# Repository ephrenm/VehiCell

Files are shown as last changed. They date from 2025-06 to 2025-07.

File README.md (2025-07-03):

**Goal:** Create a single module which combines vehicle CANbus, GPS and accelerometer data into a single stream to be stored in a cloud database using LTE CAT-M1 cellular technology.

**Current Task:** Routing

Current WIP layout:

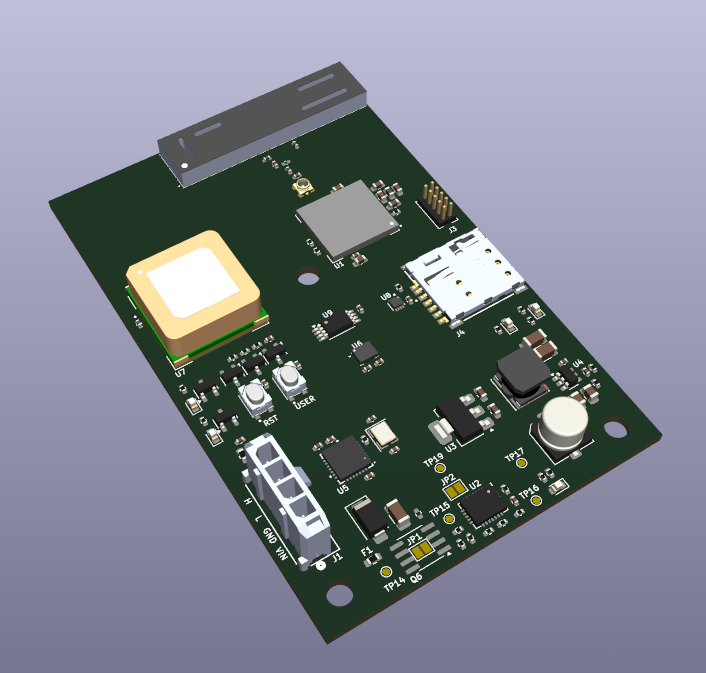
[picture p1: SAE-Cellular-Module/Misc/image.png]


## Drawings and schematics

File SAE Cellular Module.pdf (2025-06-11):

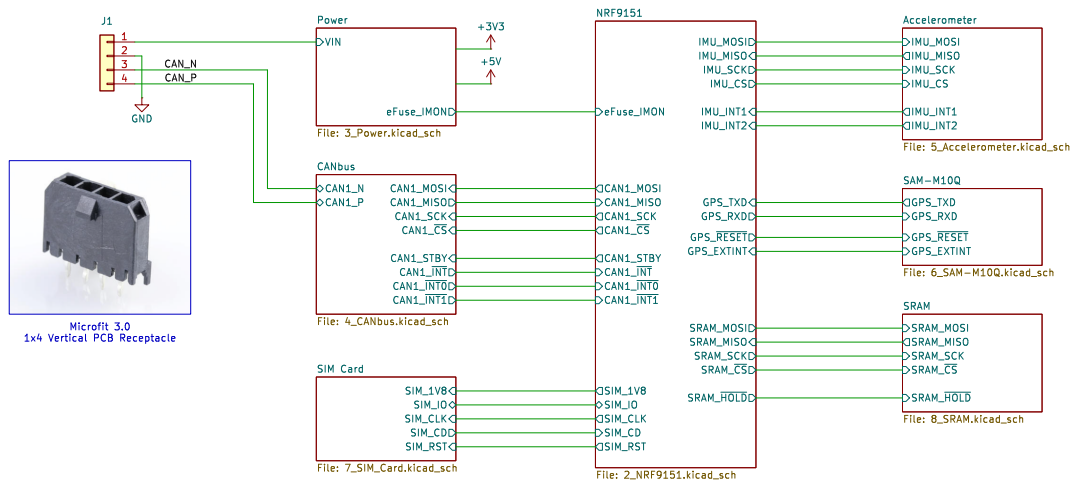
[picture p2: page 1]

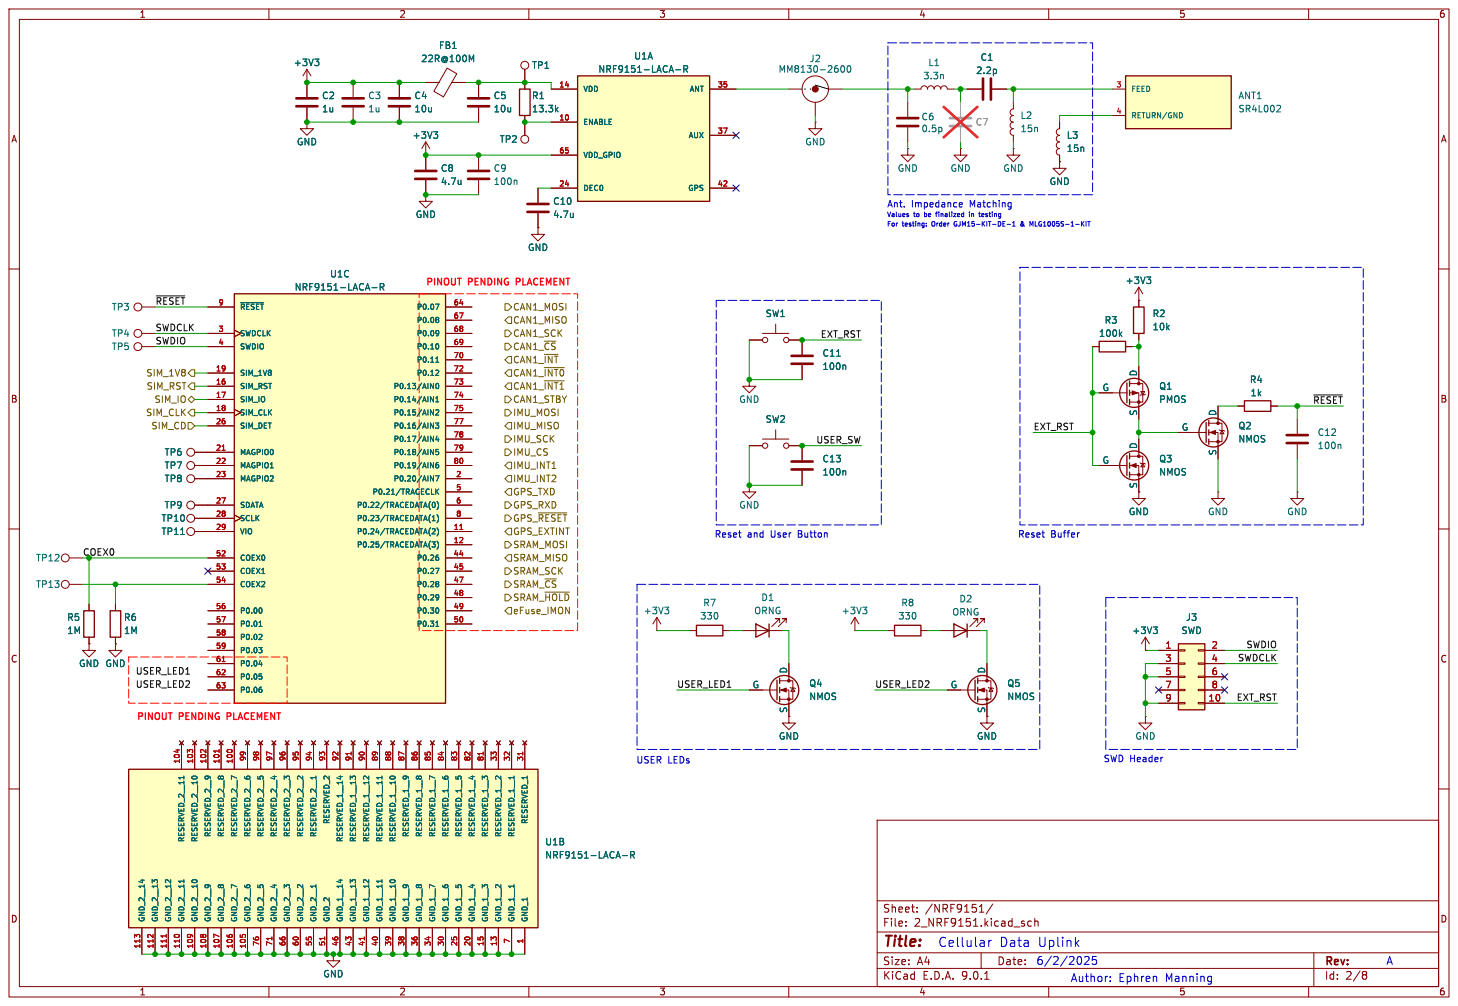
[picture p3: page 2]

Id: 2/8 Title: File: 2_NRF9151.kicad_sch Sheet: /NRF9151/ GND

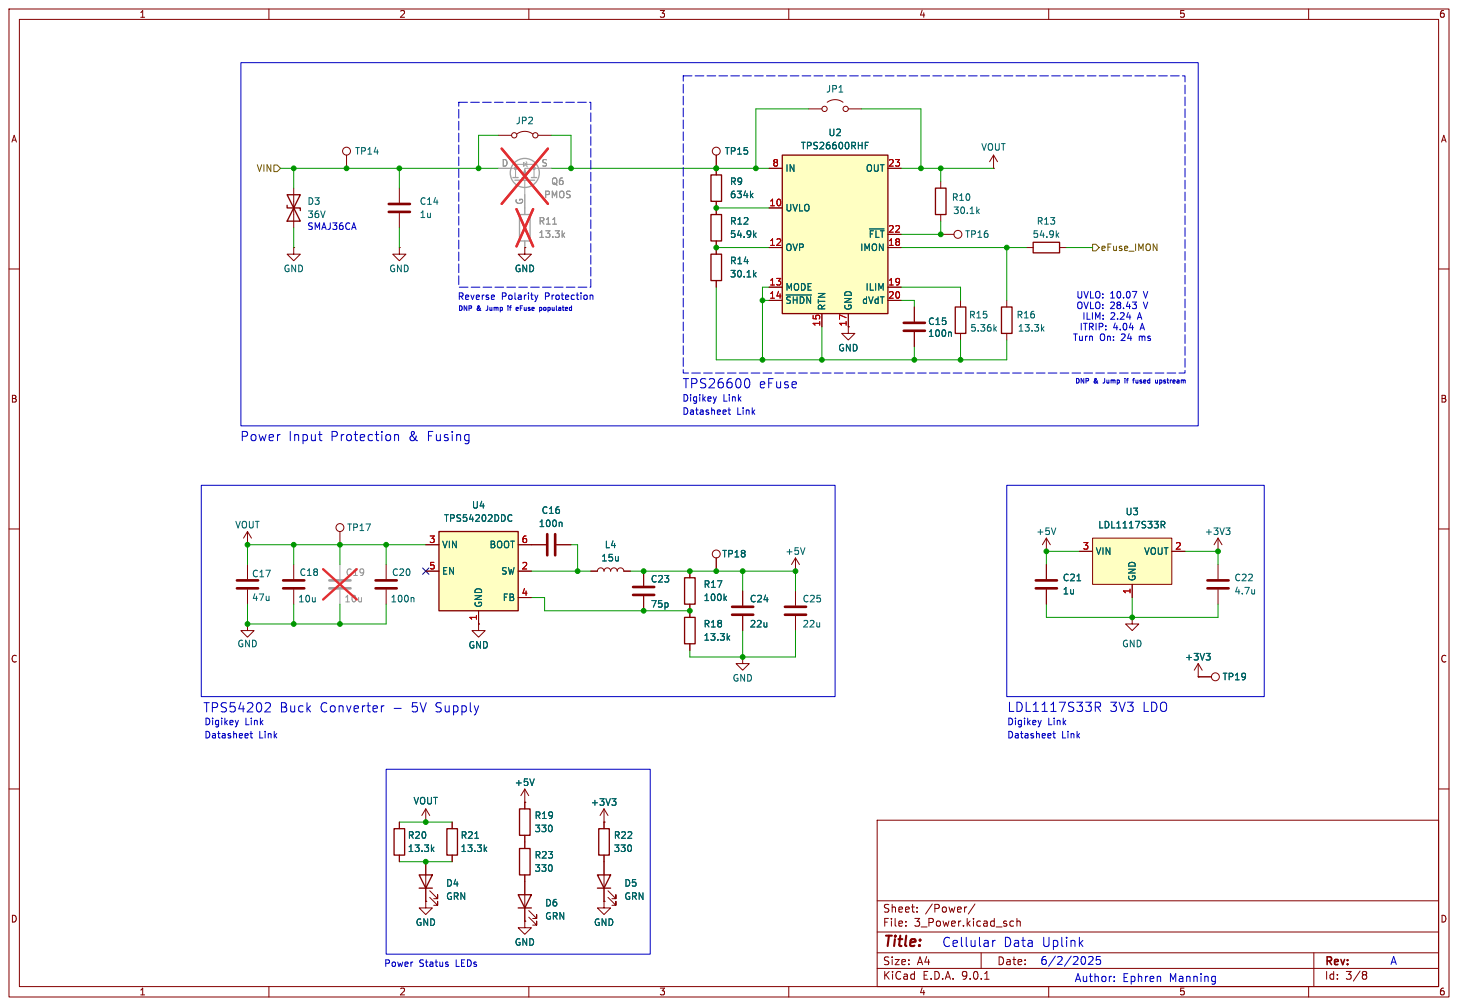
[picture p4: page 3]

1 BOOT 6 SW 2 FB 4 U4 TPS54202DDC GND

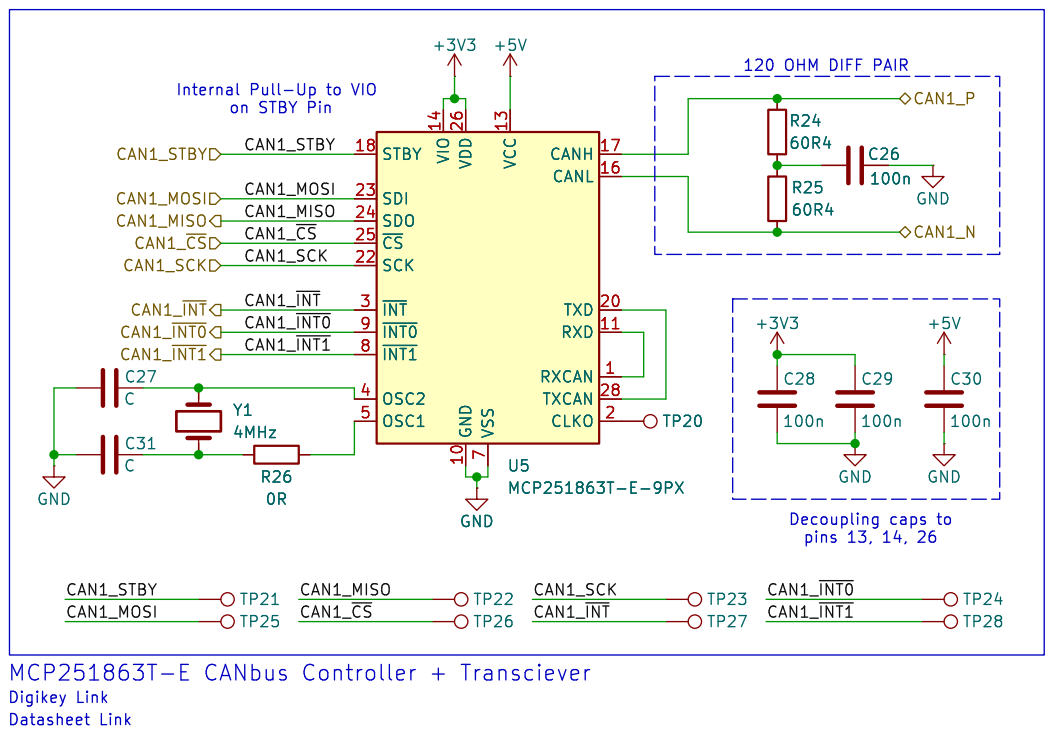
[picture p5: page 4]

7 VCC 13 CANH 17 CANL 16 TXD 20 RXD 11 RXCAN 1 TXCAN 28 CLKO 2 R24

7 VCC 13 CANH 17 CANL 16 TXD 20 RXD 11 RXCAN 1 TXCAN 28 CLKO 2 U5 MCP251863T-E-9PX

Id: 4/8 Title: File: 4_CANbus.kicad_sch Sheet: /CANbus/ GND

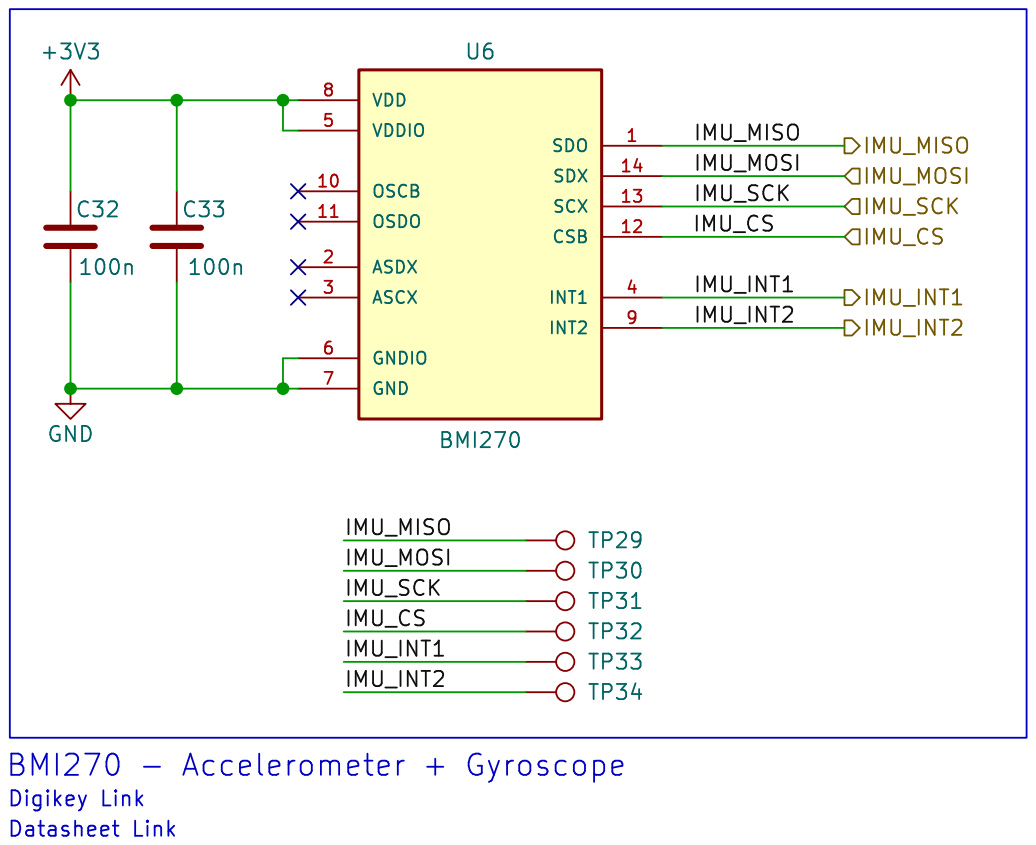
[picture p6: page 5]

Id: 5/8 Title: File: 5_Accelerometer.kicad_sch Sheet: /Accelerometer/

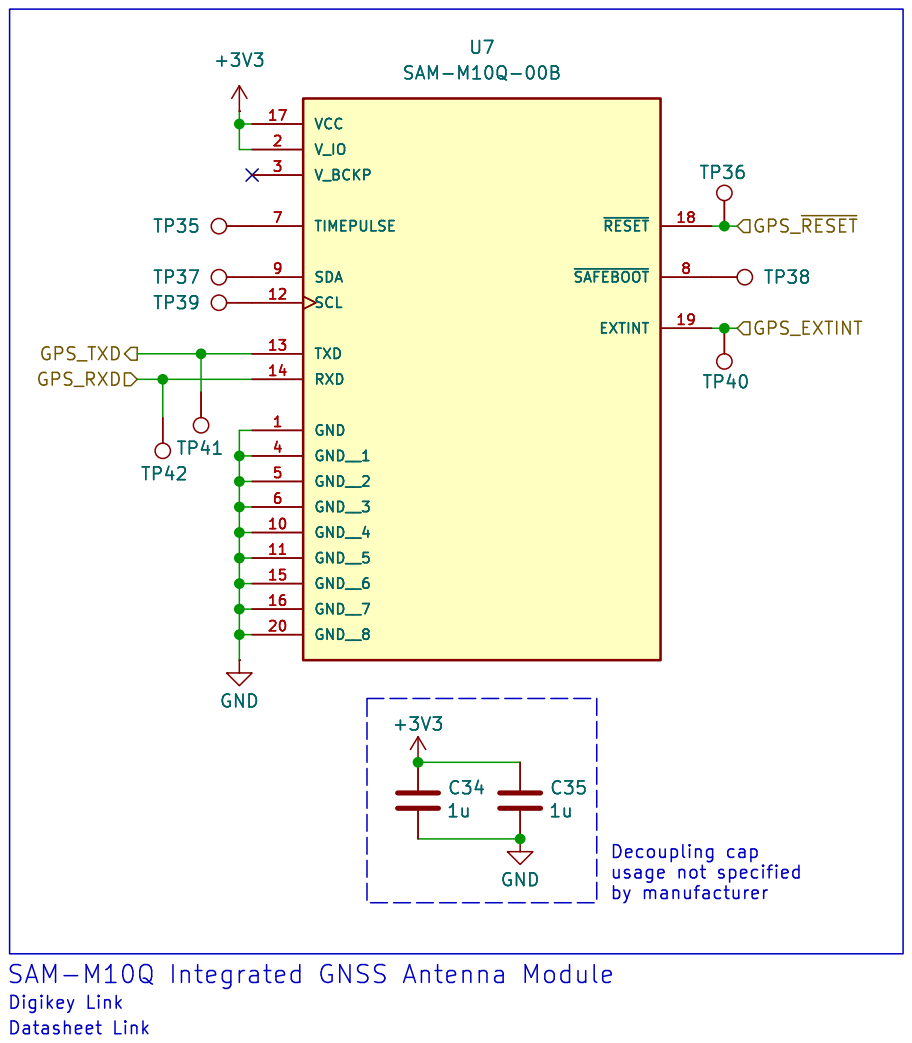
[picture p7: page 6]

Id: 6/8 Title: File: 6_SAM-M10Q.kicad_sch Sheet: /SAM-M10Q/ C35

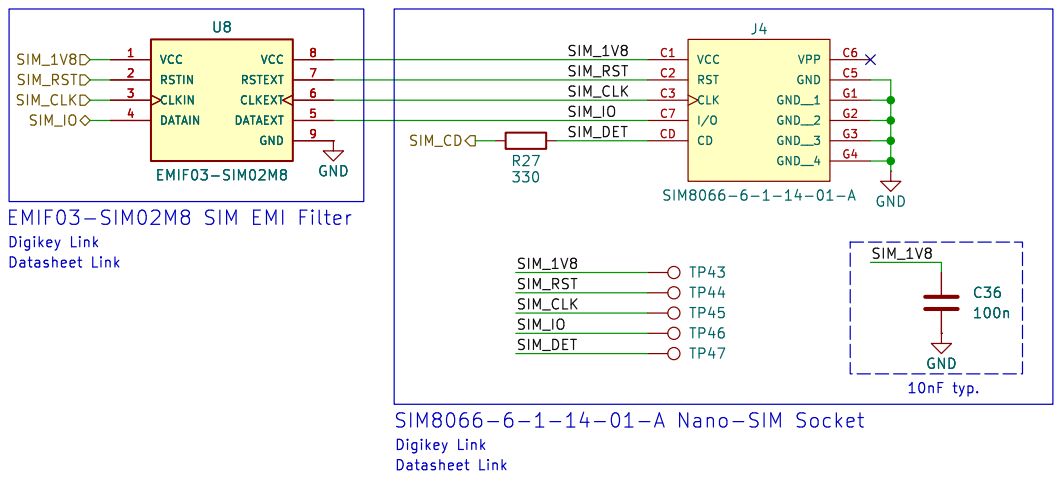
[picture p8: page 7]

VCC C1 RST C2 CLK C3

SIM_IO

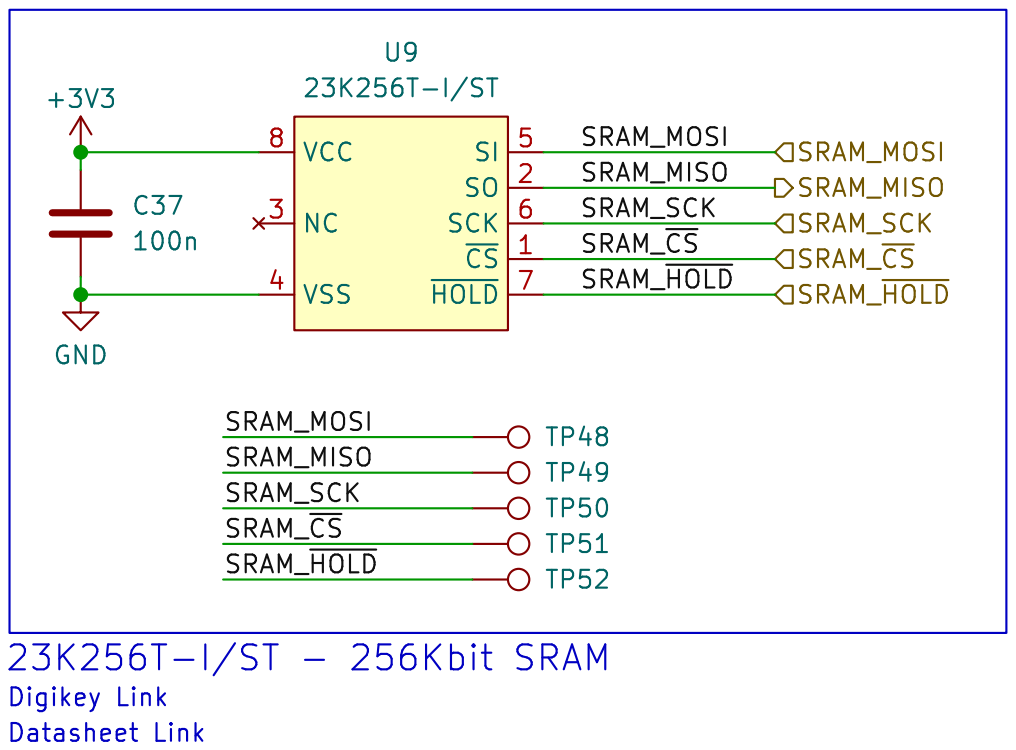
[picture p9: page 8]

Id: 8/8 Title: File: 8_SRAM.kicad_sch Sheet: /SRAM/ GND

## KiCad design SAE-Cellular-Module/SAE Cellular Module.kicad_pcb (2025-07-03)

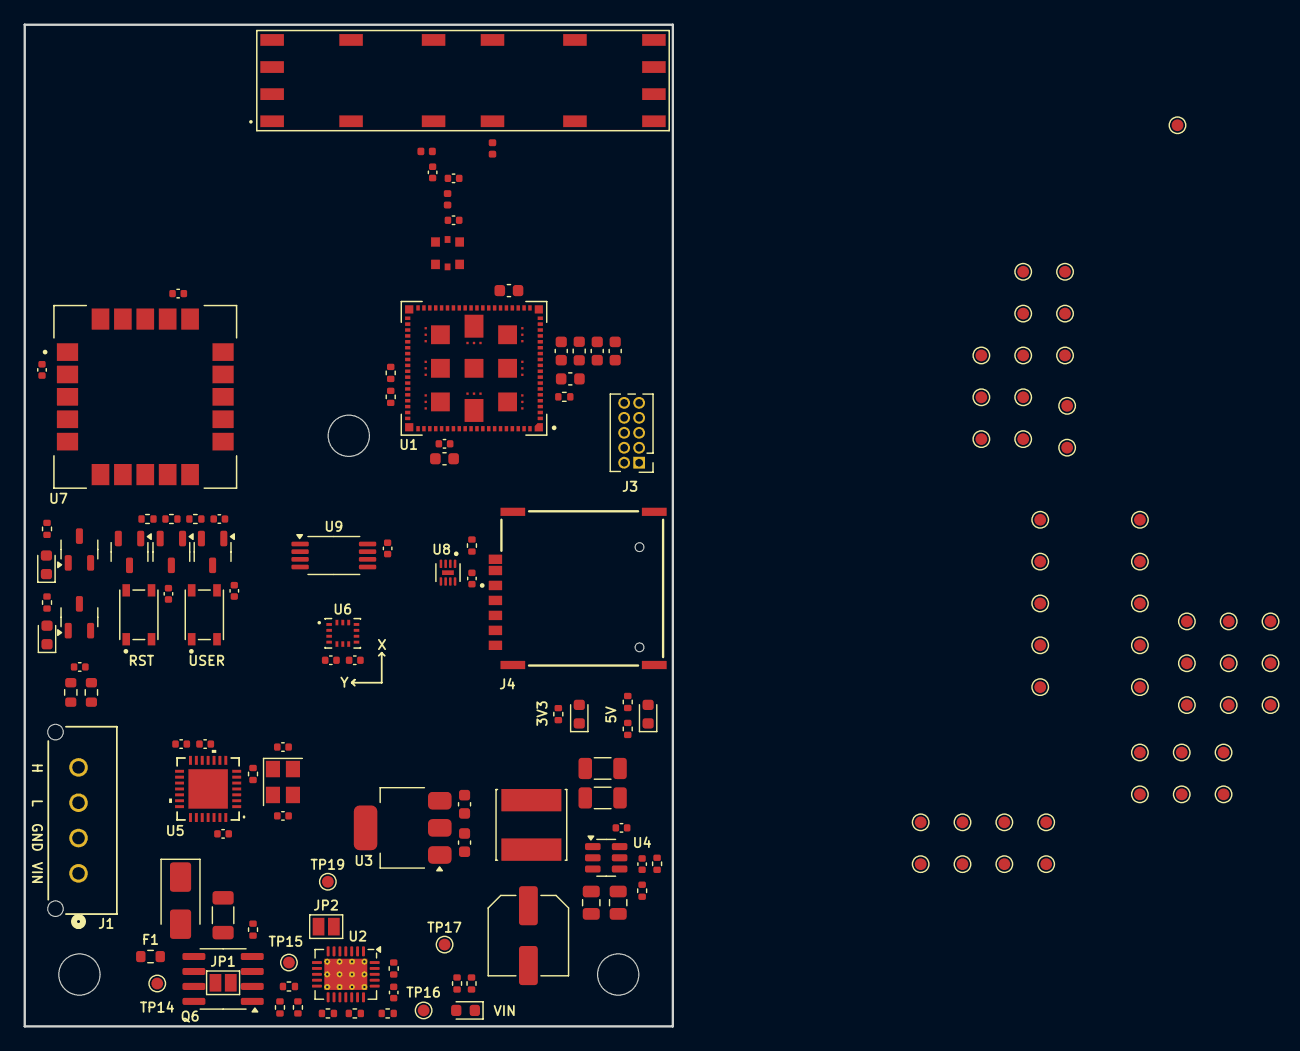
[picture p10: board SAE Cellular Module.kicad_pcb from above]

Board: 4 copper layers, 55.0 x 85.0 mm, 152 parts (0 on the bottom side), 92 nets, no tracks yet.

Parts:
ANT1: SR4L002; XCVR_SR4L002
C1, C2, C22: 1u; C_0603_1608Metric
C3, C4: 10u; C_0603_1608Metric
C5, C7, C23: 4.7u; C_0603_1608Metric
C6, C11, C12, C13, C15, C16, C26, C29, C30, C31, C32, C33, C34, C35, C36, C37: 100n; C_0402_1005Metric
C8: 2.2p; C_0402_1005Metric
C9: 0.5p; C_0402_1005Metric
C10: C_0402_1005Metric
C14: 1u; C_1206_3216Metric
C18: 47u; C_Elec_6.3x5.4
C19, C20: 10u; C_0805_2012Metric
C21: 75p; C_0402_1005Metric
C24, C25: 22u; C_1206_3216Metric
C28, C38: 36p; C_0402_1005Metric
D1, D2: ORNG; LED_0603_1608Metric
D3: 36V; D_SMA
D4, D5, D6: GRN; LED_0603_1608Metric
F1: 3A; R_0603_1608Metric
FB1: 22R@100M; L_0603_1608Metric
J1: Microfit 3.0; CONN_SD-43650-010_04_MOL
J2: MM8130-2600; MURATA_MM8130-2600RA2
J3: SWD; PinHeader_2x05_P1.27mm_Vertical
J4: SIM8066-6-1-14-01-A; GCT_SIM8066-6-1-14-01-A_REVA
JP1: Jumper_2_Bridged; SolderJumper-2_P1.3mm_Open_Pad1.0x1.5mm
JP2: Jumper_2_Open; SolderJumper-2_P1.3mm_Open_Pad1.0x1.5mm
L1: 3.3n; L_0402_1005Metric
L2, L3: 15n; L_0402_1005Metric
L4: 15u; IND_VLS6045EX-150M
Q1: DMP2004K; SOT-23-3
Q2, Q3, Q4, Q5: DMN2005K; SOT-23-3
Q6: PMOS; SOIC-8_3.9x4.9mm_P1.27mm
R1, R2, R9, R16, R18, R19, R20: 13.3k; R_0402_1005Metric
R3, R17: 100k; R_0402_1005Metric
R4, R7, R8, R21, R22, R23, R27: 330; R_0402_1005Metric
R5, R6: 1M; R_0402_1005Metric
R10: 634k; R_0402_1005Metric
R11, R14: 54.9k; R_0402_1005Metric
R12, R13: 30.1k; R_0402_1005Metric
R15: 5.36k; R_0402_1005Metric
R24, R25: 60R4; R_0603_1608Metric
R26: 0R; R_0402_1005Metric
SW1, SW2: PTS810_SJM_250_SMTR_LFS; SW_PTS810_SJM_250_SMTR_LFS
TP1, TP2, TP3, TP4, TP5, TP6, TP7, TP8, TP9, TP10, TP11, TP12, TP13, TP14, TP15, TP16, TP17, TP18, TP19, TP20, TP21, TP22, TP23, TP24, TP25, TP26, TP27, TP28, TP29, TP30, TP31, TP32, TP33, TP34, TP35, TP36, TP37, TP38, TP39, TP40, TP41, TP42, TP43, TP44, TP45, TP46, TP47, TP48, TP49, TP50, TP51, TP52: TestPoint; TestPoint_Pad_D1.0mm
U1: NRF9151-LACA-R; XCVR_NRF9151-LACA-R
U2: TPS26600RHF; Texas_RHF0024A_VQFN-24-1EP_4x5mm_P0.5mm_EP2.65x3.65mm_Therm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
U3: LDL1117S33R; SOT-223-3_TabPin2
U4: TPS54202DDC; SOT-23-6
U5: MCP251863T-E-9PX; VQFN28_9PX_3p25X3p25EPAD_MCH
U6: BMI270; XDCR_BMI270
U7: SAM-M10Q-00B; XCVR_SAM-M10Q-00B
U8: EMIF03-SIM02M8; SON40P170X150X60-9N
U9: 23K256T-I/ST; TSSOP-8_4.4x3mm_P0.65mm
Y2: 20MHz; Crystal_SMD_Abracon_ABM8G-4Pin_3.2x2.5mm

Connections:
+3V3: C1.1, C2.1, C3.1, C5.1, C6.1, C23.1, C29.1, C30.1, C32.1, C33.1, C34.1, C35.1, C37.1, FB1.1, J3.1, R2.1, R7.1, R8.1, R23.1, TP19.1, U1.65 (VDD_GPIO), U3.2 (VOUT), U5.14 (VIO), U5.26 (VDD), U6.5 (VDDIO), U6.8 (VDD), U7.2 (V_IO), U7.17 (VCC), U9.8 (VCC)
+5V: C21.1, C22.1, C24.1, C25.1, C31.1, L4.2, R17.2, R21.1, TP18.1, U3.3 (VIN), U5.13 (VCC)
/Accelerometer/IMU_CS: TP32.1, U6.12 (CSB)
/Accelerometer/IMU_INT1: TP33.1, U6.4 (INT1)
/Accelerometer/IMU_INT2: TP34.1, U6.9 (INT2)
/Accelerometer/IMU_MISO: TP29.1, U6.1 (SDO)
/Accelerometer/IMU_MOSI: TP30.1, U6.14 (SDX)
/Accelerometer/IMU_SCK: TP31.1, U6.13 (SCX)
/CAN_N: J1.3, R25.2, U5.16 (CANL)
/CAN_P: J1.4, R24.1, U5.17 (CANH)
/CANbus/CAN1_MISO: TP22.1, U5.24 (SDO)
/CANbus/CAN1_MOSI: TP25.1, U5.23 (SDI)
/CANbus/CAN1_SCK: TP23.1, U5.22 (SCK)
/CANbus/CAN1_STBY: TP21.1, U5.18 (STBY)
/CANbus/CAN1_~CS: TP26.1, U5.25 (~CS)
/CANbus/CAN1_~INT0: TP24.1, U5.9 (~INT0)
/CANbus/CAN1_~INT1: TP28.1, U5.8 (~INT1)
/CANbus/CAN1_~INT: TP27.1, U5.3 (~INT)
/NRF9151/COEX0: R5.1, TP12.1, U1.52 (COEX0)
/NRF9151/EXT_RST: C11.1, J3.10, Q1.2 (G), Q3.2 (G), R3.1, SW1.3, SW1.4
/NRF9151/GPS_EXTINT: TP40.1, U7.19 (EXTINT)
/NRF9151/GPS_RXD: TP42.1, U7.14 (RXD)
/NRF9151/GPS_TXD: TP41.1, U7.13 (TXD)
/NRF9151/GPS_~RESET: TP36.1, U7.18 (~RESET)
/NRF9151/SIM_CD: R27.2, U1.26 (SIM_DET)
/NRF9151/SWDCLK: J3.4, TP4.1, U1.3 (SWDCLK)
/NRF9151/SWDIO: J3.2, TP5.1, U1.4 (SWDIO)
/NRF9151/USER_SW: C12.1, SW2.3, SW2.4
/NRF9151/~RESET: C13.1, R4.2, TP3.1, U1.9 (~RESET)
/Power/VIN: F1.1, J1.1
/SIM Card/SIM_1V8: C36.1, J4.C1 (VCC), TP43.1, U1.19 (SIM_1V8), U8.1 (VCC), U8.8 (VCC)
/SIM Card/SIM_CLK: J4.C3 (CLK), TP45.1, U1.18 (SIM_CLK), U8.3 (CLKIN), U8.6 (CLKEXT)
/SIM Card/SIM_DET: J4.CD, R27.1, TP47.1
/SIM Card/SIM_IO: J4.C7 (I/O), TP46.1, U1.17 (SIM_IO), U8.4 (DATAIN), U8.5 (DATAEXT)
/SIM Card/SIM_RST: J4.C2 (RST), TP44.1, U1.16 (SIM_RST), U8.2 (RSTIN), U8.7 (RSTEXT)
/SRAM/SRAM_MISO: TP49.1, U9.2 (SO)
/SRAM/SRAM_MOSI: TP48.1, U9.5 (SI)
/SRAM/SRAM_SCK: TP50.1, U9.6 (SCK)
/SRAM/SRAM_~CS: TP51.1, U9.1 (~CS)
/SRAM/SRAM_~HOLD: TP52.1, U9.7 (~HOLD)
GND: C1.2, C2.2, C3.2, C4.2, C5.2, C6.2, C7.2, C9.1, C10.1, C11.2, C12.2, C13.2, C14.2, C18.2, C19.2, C20.2, C22.2, C23.2, C24.2, C25.2, C26.2, C28.1, C29.2, C30.2, C31.2, C32.2, C33.2, C34.2, C35.2, C36.2, C37.2, C38.1, D3.1 (A1), D4.1 (K), D5.1 (K), D6.1 (K), J1.2, J2.GND1 (GND), J2.GND2 (GND), J2.GND3 (GND), J2.GND4 (GND), J3.3, J3.5, J3.9, J4.C5 (GND), J4.G1 (GND__1), J4.G2 (GND__2), J4.G3 (GND__3), J4.G4 (GND__4), L2.1, L3.1, Q2.3 (S), Q3.3 (S), Q4.3 (S), Q5.3 (S), R5.2, R6.2, R9.2, R18.2, SW1.1, SW1.2, SW2.1, SW2.2, U1.1 (GND_1), U1.7 (GND_1__1), U1.13 (GND_1__2), U1.15 (GND_1__3), U1.20 (GND_1__4), U1.25 (GND_1__5), U1.30 (GND_1__6), U1.34 (GND_1__7), U1.36 (GND_1__8), U1.38 (GND_1__9), U1.39 (GND_1__10), U1.40 (GND_1__11), U1.41 (GND_1__12), U1.43 (GND_1__13), U1.46 (GND_1__14), U1.51 (GND_2), U1.55 (GND_2__1), U1.60 (GND_2__2), U1.66 (GND_2__3), U1.71 (GND_2__4), U1.76 (GND_2__5), U1.105 (GND_2__6), U1.106 (GND_2__7), U1.107 (GND_2__8), U1.108 (GND_2__9), U1.109 (GND_2__10), U1.110 (GND_2__11), U1.111 (GND_2__12), U1.112 (GND_2__13), U1.113 (GND_2__14), U2.17 (GND), U3.1 (GND), U4.1 (GND), U5.7 (VSS), U5.10 (GND), U6.6 (GNDIO), U6.7 (GND), U7.1 (GND), U7.4 (GND__1), U7.5 (GND__2), U7.6 (GND__3), U7.10 (GND__4), U7.11 (GND__5), U7.15 (GND__6), U7.16 (GND__7), U7.20 (GND__8), U8.9 (GND), U9.4 (VSS), Y2.2, Y2.4
unnamed: ANT1.3 (FEED), C8.2, L2.2
unnamed: ANT1.4 (RETURN/GND), L3.2
unnamed: C9.2, J2.IN, L1.1
unnamed: C8.1, C10.2, L1.2
unnamed: C26.1, R24.2, R25.1
unnamed: C28.2, R26.1, Y2.1
unnamed: D1.2 (A), R7.2
unnamed: D1.1 (K), Q4.1 (D)
unnamed: D2.2 (A), R8.2
unnamed: D2.1 (K), Q5.1 (D)
unnamed: C14.1, D3.2 (A2), F1.2, JP1.1 (A), Q6.5 (D), Q6.6 (D), Q6.7 (D), Q6.8 (D), TP14.1
unnamed: D4.2 (A), R19.2, R20.2
unnamed: D5.2 (A), R22.2
unnamed: D6.2 (A), R23.2
unnamed: JP1.2 (B), JP2.1 (A), Q6.1 (S), Q6.2 (S), Q6.3 (S), R10.1, TP15.1, U2.8 (IN), U2.9 (IN)
unnamed: Q1.1 (D), R2.2, R3.2
unnamed: Q1.3 (S), Q2.2 (G), Q3.1 (D)
unnamed: Q2.1 (D), R4.1
unnamed: Q6.4 (G), R9.1
unnamed: R21.2, R22.1
unnamed: J2.OUT, U1.35 (ANT)
unnamed: C7.1, U1.24 (DEC0)
unnamed: R1.2, TP2.1, U1.10 (ENABLE)
unnamed: C4.1, FB1.2, R1.1, TP1.1, U1.14 (VDD)
unnamed: R6.1, TP13.1, U1.54 (COEX2)
unnamed: TP6.1, U1.21 (MAGPIO0)
unnamed: TP7.1, U1.22 (MAGPIO1)
unnamed: TP8.1, U1.23 (MAGPIO2)
unnamed: TP10.1, U1.28 (SCLK)
unnamed: TP9.1, U1.27 (SDATA)
unnamed: TP11.1, U1.29 (VIO)
unnamed: R15.1, U2.19 (ILIM)
unnamed: R14.1, R16.1, U2.18 (IMON)
unnamed: C15.2, R12.2, R15.2, R16.2, U2.13 (MODE), U2.14 (~SHDN), U2.15 (RTN), U2.25 (RTN)
unnamed: R11.2, R12.1, U2.12 (OVP)
unnamed: R10.2, R11.1, U2.10 (UVLO)
unnamed: C15.1, U2.20 (dVdT)
unnamed: R13.2, TP16.1, U2.22 (~FLT)
unnamed: C16.1, U4.6 (BOOT)
unnamed: C21.2, R17.1, R18.1, U4.4 (FB)
unnamed: C16.2, L4.1, U4.2 (SW)
unnamed: TP20.1, U5.2 (CLKO)
unnamed: R26.2, U5.5 (OSC1)
unnamed: C38.2, U5.4 (OSC2), Y2.3
unnamed: U5.1 (RXCAN), U5.11 (RXD)
unnamed: U5.20 (TXD), U5.28 (TXCAN)
unnamed: TP39.1, U7.12 (SCL)
unnamed: TP37.1, U7.9 (SDA)
unnamed: TP35.1, U7.7 (TIMEPULSE)
unnamed: TP38.1, U7.8 (~SAFEBOOT)
VOUT: C18.1, C19.1, C20.1, JP2.2 (B), R13.1, R19.1, R20.1, TP17.1, U2.23 (OUT), U2.24 (OUT), U4.3 (VIN)

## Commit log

2025-06-11 Initial Push
    [2_NRF9151.kicad_sch, 3_Power.kicad_sch, 4_CANbus.kicad_sch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]
2025-07-03 Added initial component placements
    [2_NRF9151.kicad_sch, 3_Power.kicad_sch, 4_CANbus.kicad_sch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]
